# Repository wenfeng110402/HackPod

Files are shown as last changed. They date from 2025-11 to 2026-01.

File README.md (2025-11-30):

# HackPod

HackPod is my small MP3 player. It is inspired by iPod shuffle. I want a tiny music thing I can carry anywhere, so I made this. I am a middle school student. This project is for learning and for fun.

## Why I made it

- I like simple music players.
- iPod shuffle is cool and cute.
- I want to learn electronics and code.

## What it does

- Plays MP3 songs from a micro SD card.
- Buttons: Play/Pause, Next, Previous, Volume Up, Volume Down, and one extra "Hack" button.
- I2S audio to DAC/amp and a small speaker.
- LED status light.
- Battery check by ADC (shows high / medium / low).

## Parts I use

- ESP32 (microcontroller)
- Micro SD card slot
- 6 buttons
- Battery (lithium)
- Small amplifier + speaker
- My small PCB (see files in `PCB/`)

## Project files

- Firmware: `FIRMWARE/HackPod/`
- PCB files: `PCB/`
- 3D shell model: `3DSHELL/`

## Status

- Hardware works.
- Firmware is simple now. I will keep improving.

## Screenshots

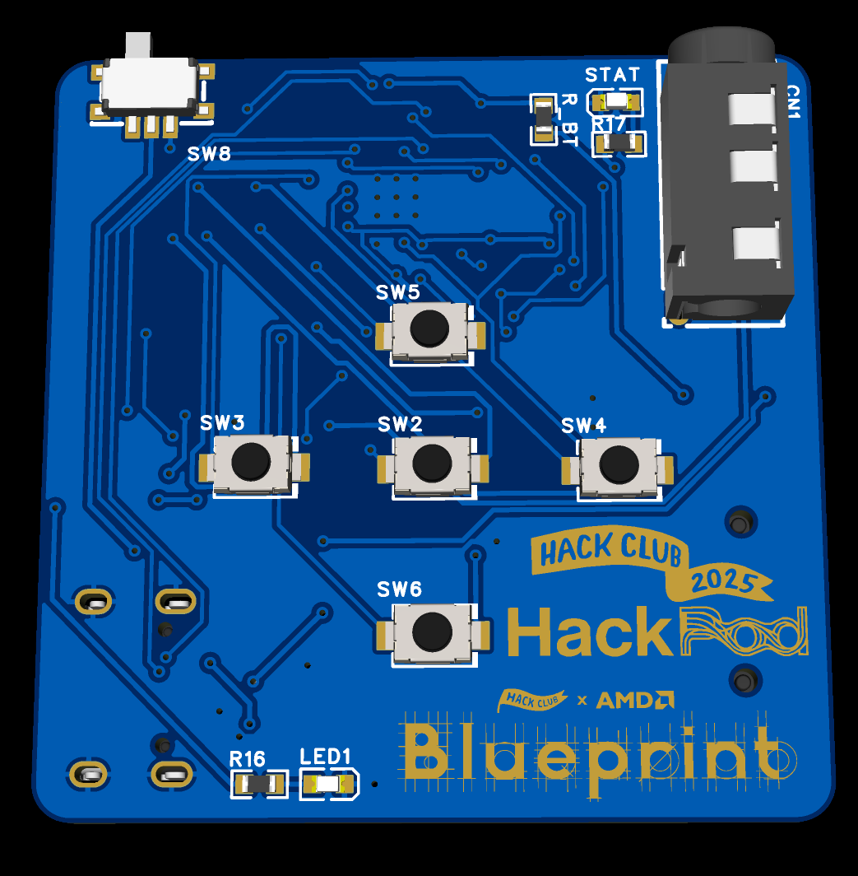
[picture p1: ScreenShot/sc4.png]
sc1

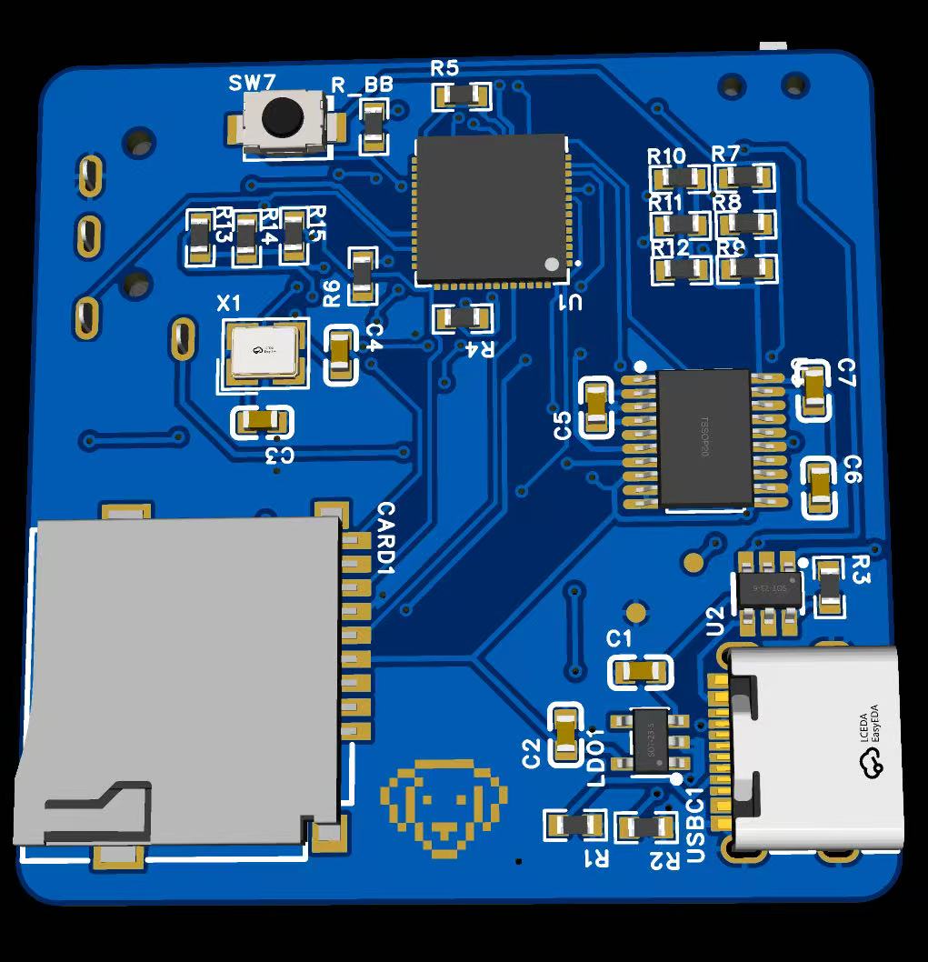
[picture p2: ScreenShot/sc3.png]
sc2

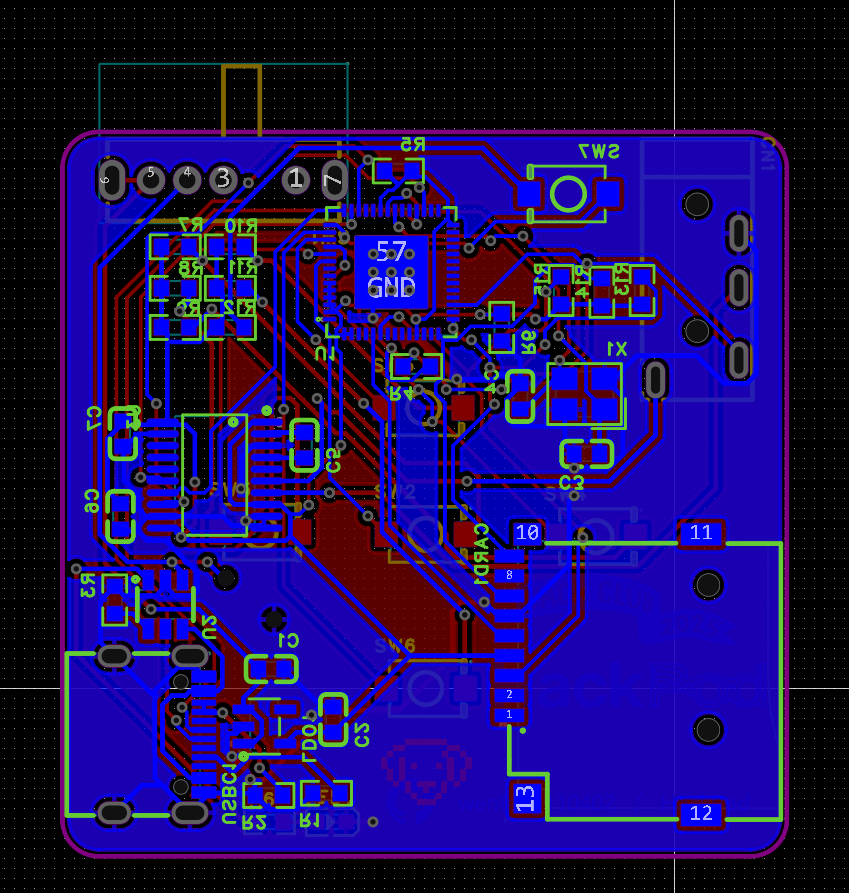
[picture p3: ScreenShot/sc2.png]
sc3

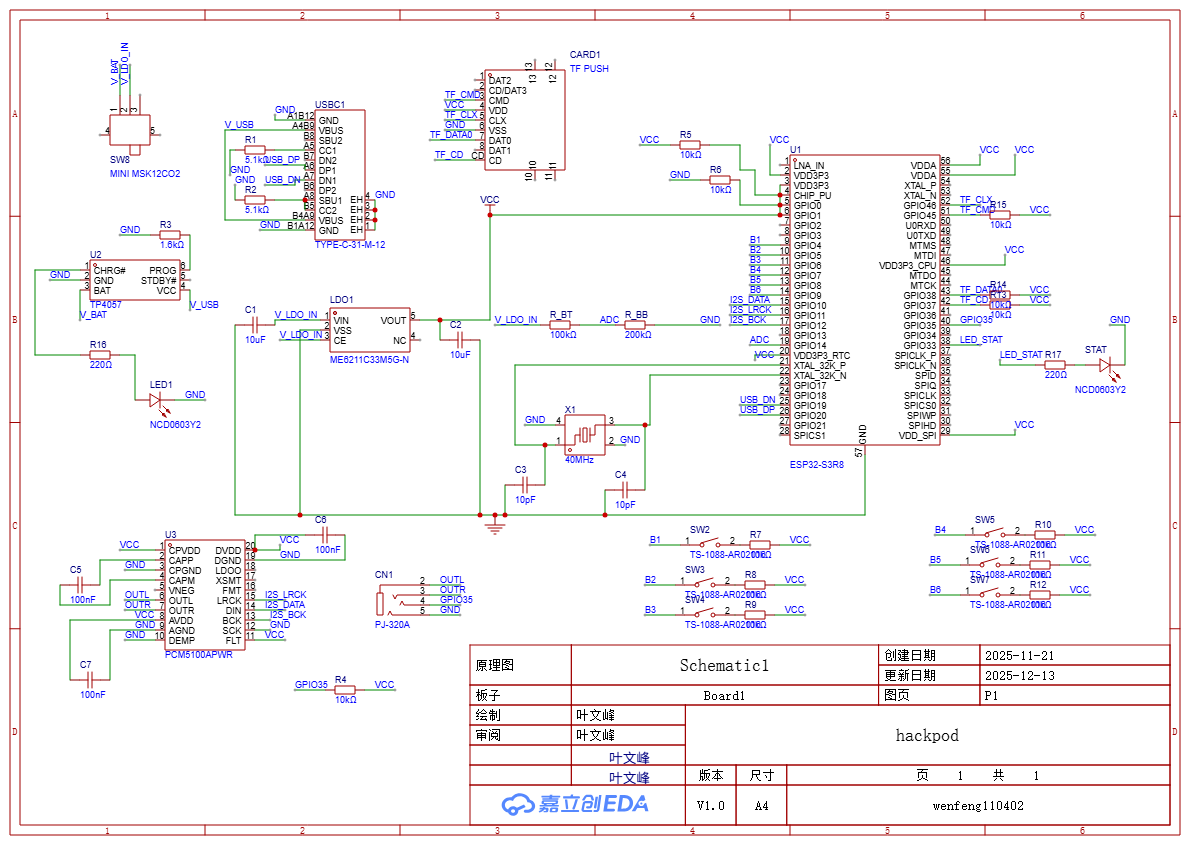
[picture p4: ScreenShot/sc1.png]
sc4


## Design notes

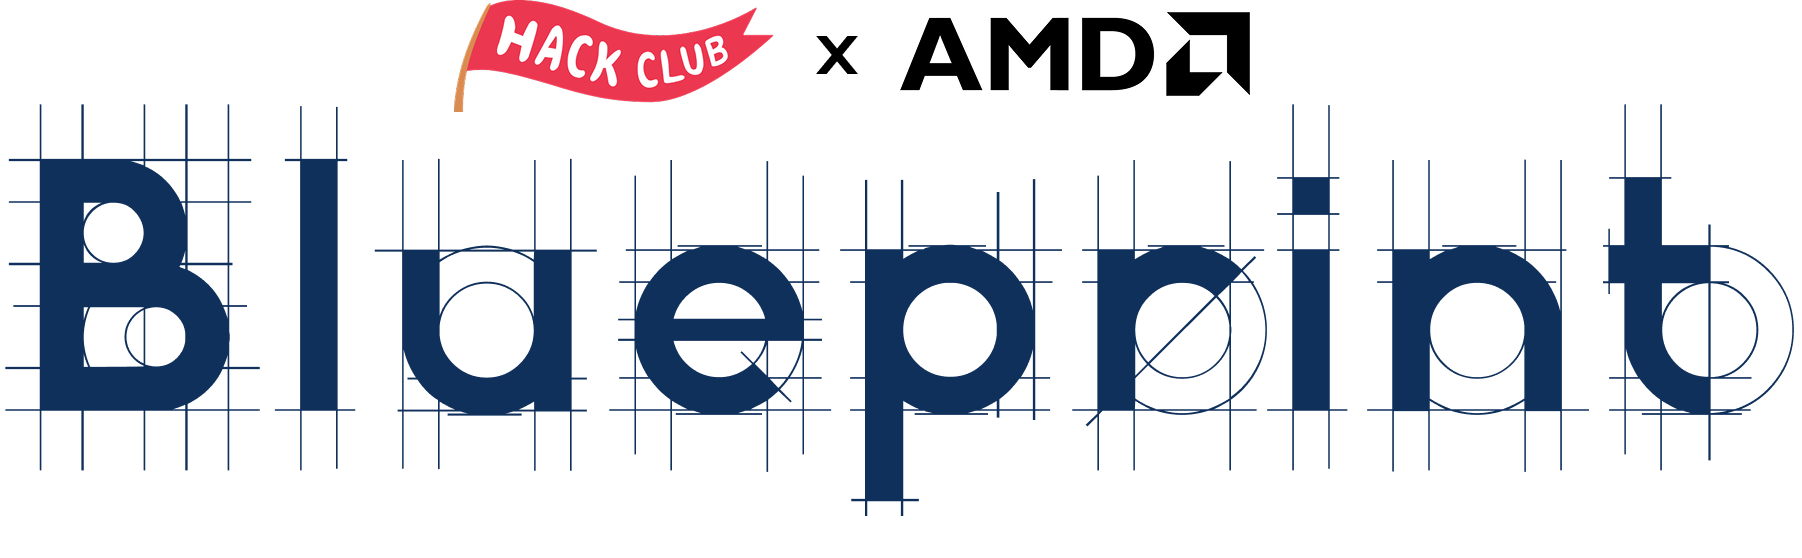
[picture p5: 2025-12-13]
posters/drive-download-20251213T033350Z-1-001/Wordmark Partnership.png

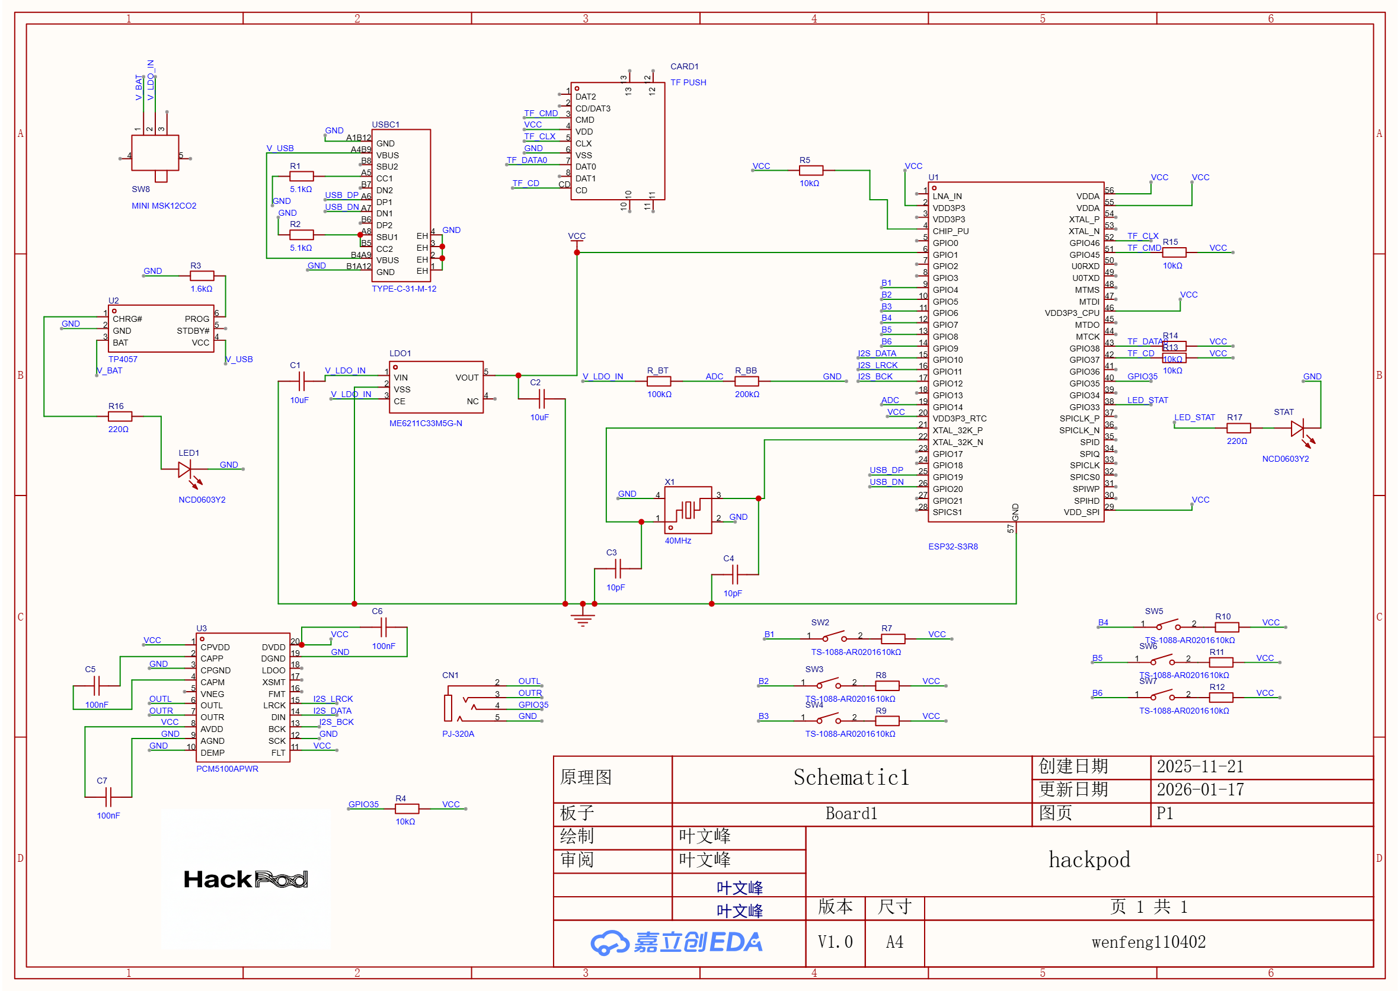
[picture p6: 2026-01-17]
PCB/SCH_Schematic1_1-P1.png

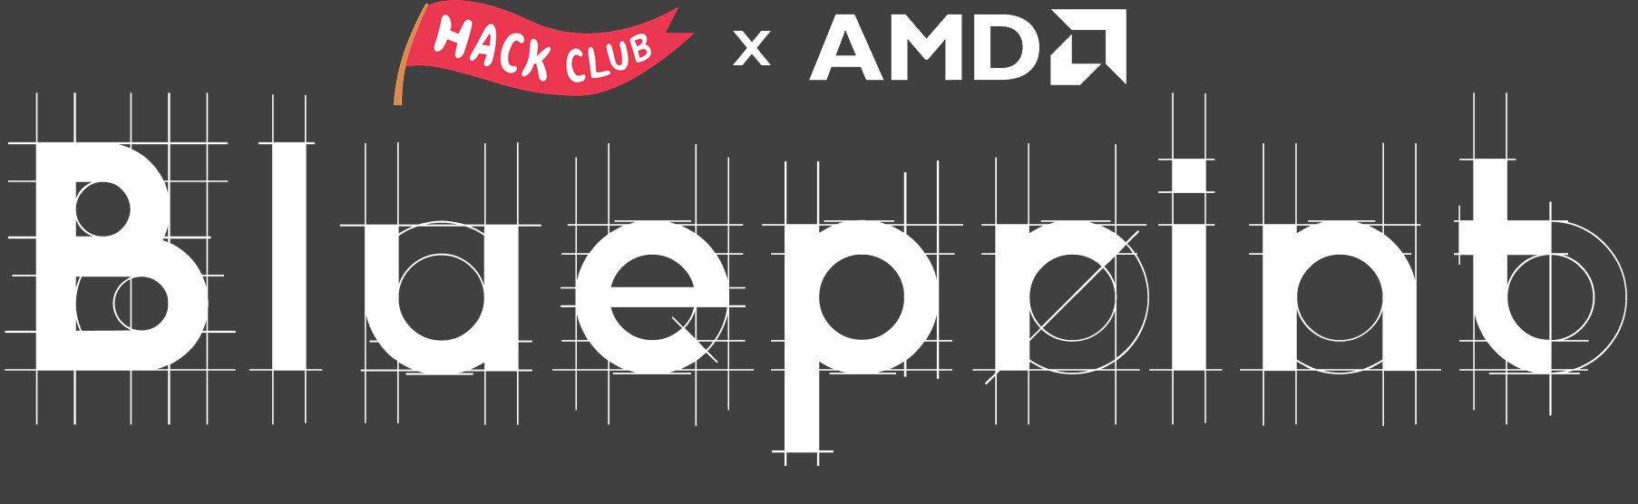
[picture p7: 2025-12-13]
posters/drive-download-20251213T033350Z-1-001/Wordmark Partnership-1.png

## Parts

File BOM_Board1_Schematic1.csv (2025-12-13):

No. | Quantity | Comment | Designator | Footprint | Value | Manufacturer Part | Manufacturer | Supplier Part | Supplier | Price(USD)
1 | 2 | 10uF | C1,C2 | C0603 | 10uF | CL10A106MA8NRNC | SAMSUNG(三星) | C96446 | LCSC | 0.3
2 | 2 | 10pF | C3,C4 | C0603 | 10pF | CL10C100JB8NNNC | SAMSUNG(三星) | C1634 | LCSC | 0.443
3 | 3 | 100nF | C5,C6,C7 | C0603 | 100nF | CL10B104KB8NNNC | SAMSUNG(三星) | C1591 | LCSC | 0.23
4 | 1 | TF PUSH | CARD1 | TF-SMD_TF-PUSH |  | TF PUSH | SHOU HAN(首韩) | C393941 | LCSC | 0.57
5 | 1 | PJ-320A | CN1 | AUDIO-TH_PJ-320A_C49284721 |  | PJ-320A | XUNPU(讯普) | C49284721 | LCSC | 0.57
6 | 1 | ME6211C33M5G-N | LDO1 | SOT-23-5_L3.0-W1.7-P0.95-LS2.8-BL |  | ME6211C33M5G-N | MICRONE(南京微盟) | C82942 | LCSC | 0.43
7 | 2 | NCD0603Y2 | LED1,STAT | LED0603-RD |  | NCD0603Y2 | 国星光电 | C89811 | LCSC | 0.08
8 | 2 | 5.1kΩ | R1,R2 | R0603 | 5.1kΩ | 0603WAF5101T5E | UNI-ROYAL(厚声) | C23186 | LCSC | 0.09
9 | 1 | 1.6kΩ | R3 | R0603 | 1.6kΩ | ERA3AEB162V | PANASONIC(松下) | C473232 | LCSC | 0.34
10 | 12 | 10kΩ | R4,R5,R6,R7,R8,R9,R10,R11,R12,R13,R14,R15 | R0603 | 10kΩ | 0603WAF1002T5E | UNI-ROYAL(厚声) | C25804 | LCSC | 0.08
11 | 2 | 220Ω | R16,R17 | R0603 | 220Ω | FRC0603J221 TS | FOJAN(富捷) | C2907127 | LCSC | 0.07
12 | 1 | 200kΩ | R_BB | R0603 | 200kΩ | ERA3AEB204V | PANASONIC(松下) | C473261 | LCSC | 0.32
13 | 1 | 100kΩ | R_BT | R0603 | 100kΩ | ERJ3EKF1003V | PANASONIC(松下) | C189597 | LCSC | 0.53
14 | 1 | SK13D07VG4 | SW8 | SW-TH_SK13D07VG4 |  | SK13D07VG4 | SHOU HAN(首韩) | C2681581 | LCSC | 0.57
15 | 6 | TS-1088-AR02016 | SW2,SW3,SW4,SW5,SW6,SW7 | SW-SMD_L3.9-W3.0-P4.45 |  | TS-1088-AR02016 | XUNPU(讯普) | C720477 | LCSC | 0.76
16 | 5 | ESP32-S3R8 | U1 | QFN-56_L7.0-W7.0-P0.40-TL-EP4.0 |  | ESP32-S3R8 | ESPRESSIF(乐鑫) | C2913194 | LCSC | 9.04
17 | 10 | TP4057 | U2 | SOT-23-6_L2.9-W1.6-P0.95-LS2.8-BR |  | TP4057 | UMW(友台半导体) | C725791 | LCSC | 0.35
18 | 5 | PCM5100APWR | U3 | TSSOP-20_L6.5-W4.4-P0.65-LS6.4-BL |  | PCM5100APWR | TI(德州仪器) | C131154 | LCSC | 4.25
19 | 1 | MINI MSK12CO2 | SW8 | SW-SMD_MSK12CO2 |  | MINI MSK12CO2 | SHOU HAN(首韩) | C2681570 | LCSC | 0.5
20 | 1 | TYPE-C-31-M-12 | USBC1 | USB-C_SMD-TYPE-C-31-M-12_1 |  | TYPE-C-31-M-12 | 韩国韩荣 | C165948 | LCSC | 0.8
21 | 10 | 40MHz | X1 | CRYSTAL-SMD_4P-L3.2-W2.5-BL | 40MHz | XL2EL89CPI-111YLC-40M | YXC(扬兴晶振) | C5444549 | LCSC | 0.53
 |  |  |  |  |  |  |  |  | BOM | 20.85
 |  |  |  |  |  |  |  |  | PCB | 44.71
 |  |  |  |  |  |  |  |  |  | 65.56

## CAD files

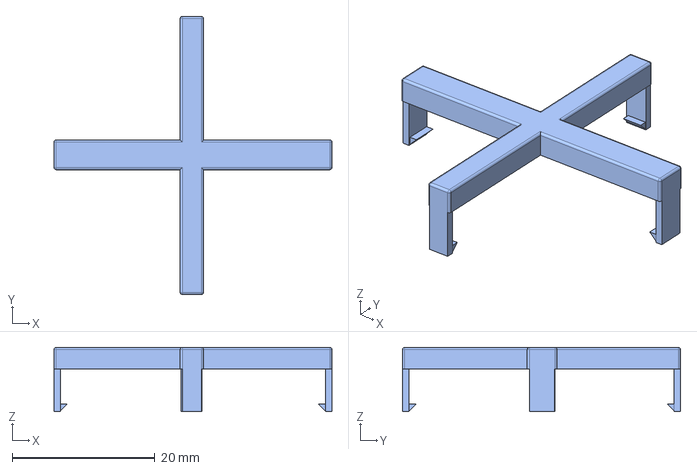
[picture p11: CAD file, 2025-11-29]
3DSHELL/shapr3d_HackPod.step
39.0 x 39.0 x 9.00 mm

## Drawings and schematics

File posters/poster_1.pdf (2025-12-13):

# Get a $400 grant

# to build a

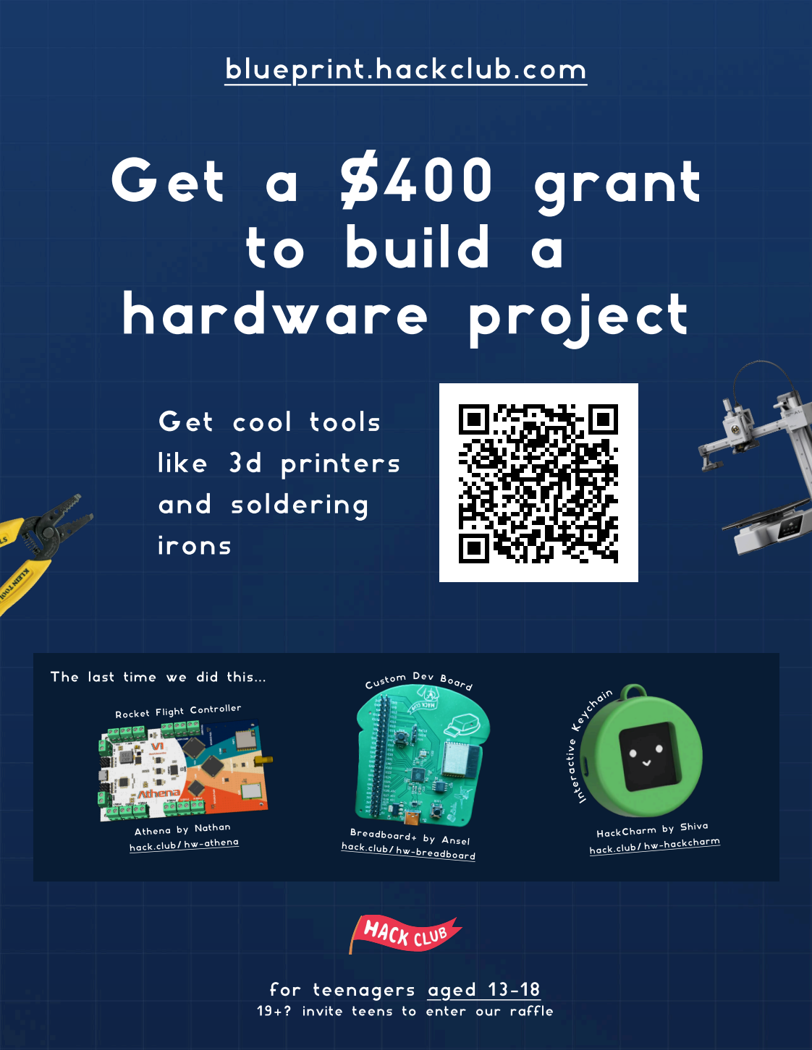
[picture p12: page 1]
hardware project; teractiv; Keychain

blueprint.hackclub.com

Get cool tools
like 3d printers
and soldering
irons

The last time we did this...

Custom Dev Board

Rocket Flight Controller

Athena by Nathan

HackCharm by Shiva

hack.club/hw-athena Breadboard+ by Ansel

hack.club/hw-breadboard

hack.club/hw-hackcharm

for teenagers aged 13-18

19+? invite teens to enter our raffle

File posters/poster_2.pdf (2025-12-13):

# Get a $400 grant

# to build a

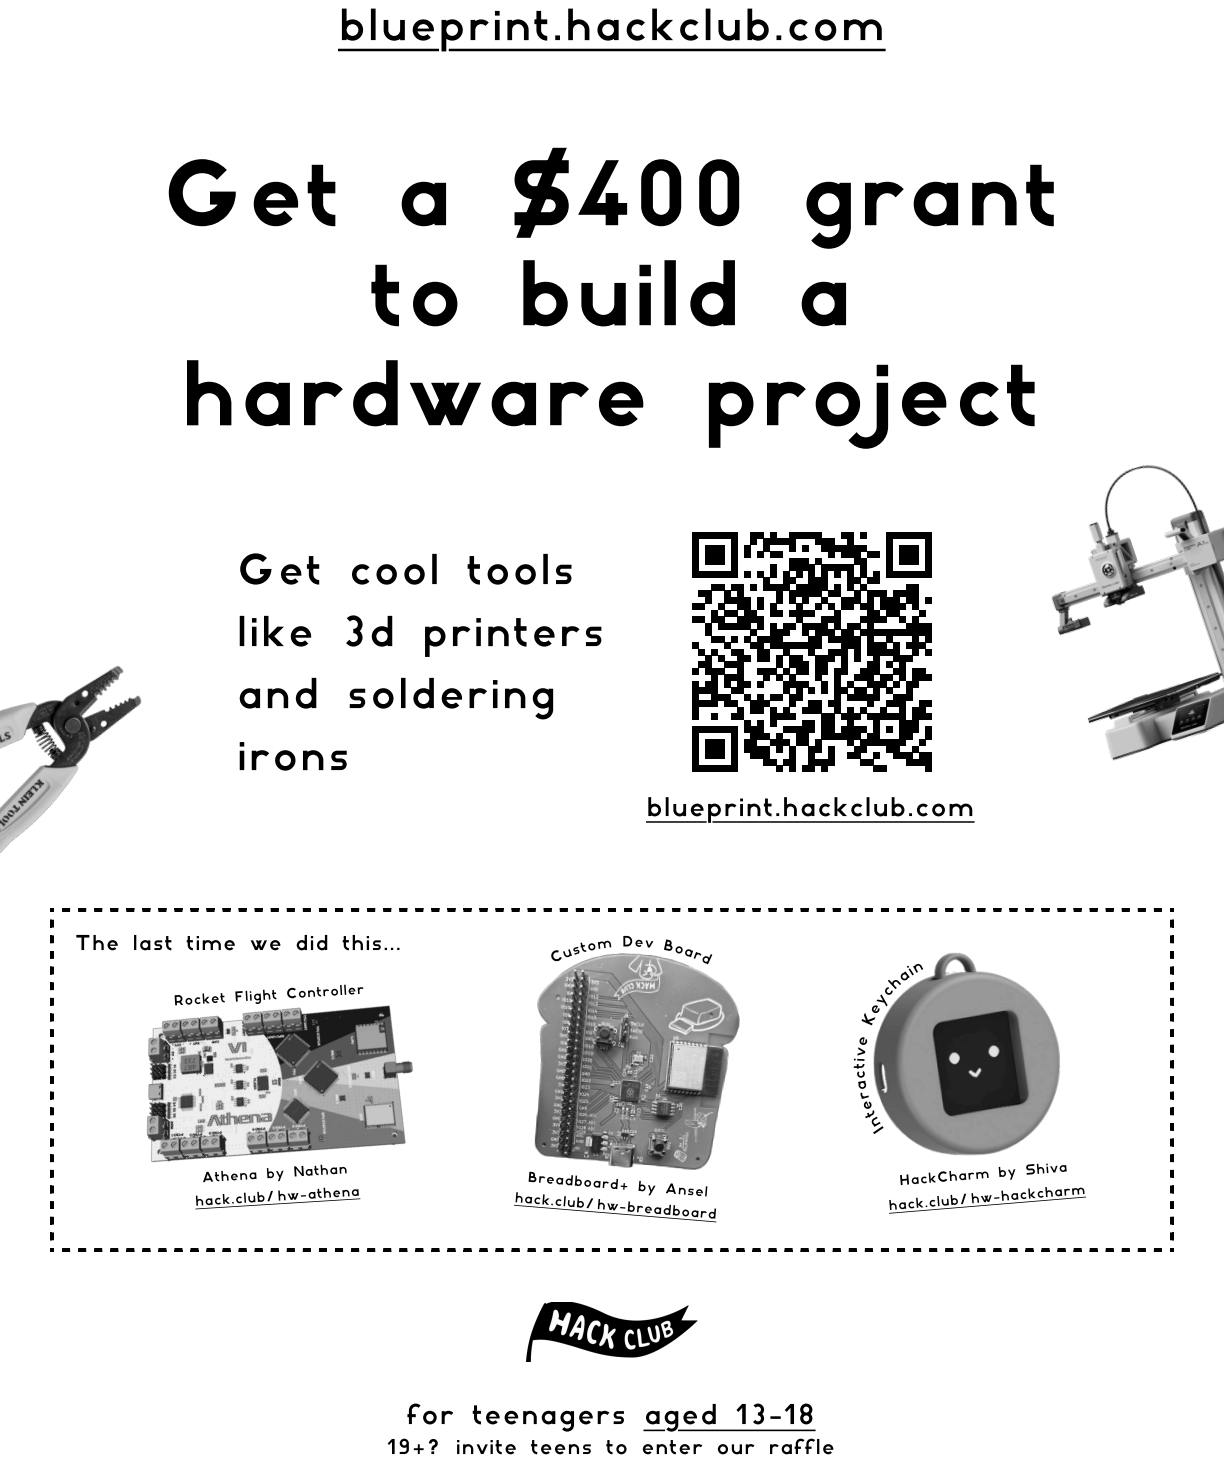
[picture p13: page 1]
hardware project; teractiv; Keychain; like 3d printers; and soldering; irons

blueprint.hackclub.com

Get cool tools

The last time we did this...

Custom Dev Board

Rocket Flight Controller

HackCharm by Shiva

hack.club/hw-athena Breadboard+ by Ansel

Athena by Nathan

hack.club/hw-breadboard

hack.club/hw-hackcharm

for teenagers aged 13-18

19+? invite teens to enter our raffle

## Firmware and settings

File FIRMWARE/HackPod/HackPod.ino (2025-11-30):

#include "config.h"
#include "PowerManager.h"
#include "InputManager.h"
#include "AudioManager.h"

// 实例化全局管理器对象
PowerManager powerMgr;
InputManager inputMgr;
// audioMgr 已经在 AudioManager.cpp 中定义

// 全局变量：
bool isAutomixMode = false; // 是否处于 Automix 模式 (现在称为随机播放模式)
static bool hasLowBatteryWarningPlayed = false; // 用于控制低电量警告只播放一次

// --- 核心逻辑：处理按键动作 ---
void handleInputAction(const char* action) {
    Serial.printf("Action: %s\n", action);

    if (strcmp(action, "PLAY") == 0) {
        audioMgr.playPause();
    } else if (strcmp(action, "NEXT") == 0) {
        audioMgr.next();
    } else if (strcmp(action, "PREV") == 0) {
        audioMgr.prev();
    } else if (strcmp(action, "VOLUP") == 0) {
        audioMgr.changeVolume(1);
    } else if (strcmp(action, "VOLDOWN") == 0) {
        audioMgr.changeVolume(-1);
    } else if (strcmp(action, "HACK_CLICK") == 0) {
        // Hack键单击：播报电量
        String batStatusFilePrefix = powerMgr.getBatteryStatusString(); // 返回 bv00, bv01 等
        String audioFile = String(SYSTEM_AUDIO_DIR) + "/" + batStatusFilePrefix + ".wav"; // 拼接成 /system/bv00.wav
        audioMgr.playSystemSound(audioFile);
    } else if (strcmp(action, "HACK_LONG") == 0) {
        // Hack键长按：切换播放模式 (随机播放 / 循环播放)
        PlayMode currentMode = audioMgr.getPlayMode();
        if (currentMode == PLAYMODE_LOOP_ALL) {
            audioMgr.setPlayMode(PLAYMODE_RANDOM);
            audioMgr.playSystemSound(String(SYSTEM_AUDIO_DIR) + "/sn02.wav"); // 播放切换到随机模式的提示音
            Serial.println("Switched to Random Play Mode.");
        } else { // 当前是随机播放模式，切换回循环播放
            audioMgr.setPlayMode(PLAYMODE_LOOP_ALL);
            audioMgr.playSystemSound(String(SYSTEM_AUDIO_DIR) + "/sn03.wav"); // 播放切换到循环模式的提示音
            Serial.println("Switched to Loop All Mode.");
        }
        // LED 指示：长按 Hack 键时，LED 闪烁一下或改变状态
        digitalWrite(LED_STAT_PIN, HIGH);
        delay(100);
        digitalWrite(LED_STAT_PIN, LOW);
    }
}

void setup() {
    Serial.begin(115200);
    Serial.println("\n--- HackPod Starting ---");

    // 初始化 LED
    pinMode(LED_STAT_PIN, OUTPUT);
    digitalWrite(LED_STAT_PIN, LOW);

    // 初始化各个模块
    powerMgr.begin();
    // 传入回调函数，让 InputManager 知道按键触发时通知谁
    inputMgr.begin(handleInputAction);
    audioMgr.begin();

    // 播放开机音 (如果需要，可以在 system 文件夹放一个 power_on.wav)
    // audioMgr.playSystemSound(String(SYSTEM_AUDIO_DIR) + "/power_on.wav");

    Serial.println("--- Ready ---");
}

void loop() {
    // 必须在主循环中不断调用这些函数
    audioMgr.loop();
    inputMgr.loop();

    // --- 1. 电池状态更新与打印 & 低电量警告 ---
    // 每隔5秒读取并打印一次电池信息
    static unsigned long lastBatteryReadTime = 0;
    if (millis() - lastBatteryReadTime > 5000) { // 每5秒读取一次
        float voltage = powerMgr.getBatteryVoltage();
        int percentage = powerMgr.getBatteryPercentage();
        // getBatteryStatusString 现在返回 "bv00" 等文件名部分，这里仅用于打印
        String statusPrefix = powerMgr.getBatteryStatusString(); 

        Serial.print("Battery: ");
        Serial.print(voltage, 2); 
        Serial.print("V (");
        Serial.print(percentage);
        Serial.print("%), Status: ");
        Serial.println(statusPrefix); // 打印文件名后缀

        // 低电量警告逻辑 (仅当电量低于10%且未播放过警告时才播放)
        if (percentage <= 10 && !hasLowBatteryWarningPlayed) {
            audioMgr.playSystemSound(String(SYSTEM_AUDIO_DIR) + "/bn00.wav"); // 播放低电量警告音
            Serial.println("!! Low Battery Warning (10%) !!");
            hasLowBatteryWarningPlayed = true; // 设置标志，防止重复播放
        } else if (percentage > 10) {
            hasLowBatteryWarningPlayed = false; // 电量回升后重置警告标志
        }

        // LED 指示：如果电量低于20%，LED 慢速闪烁
        if (percentage < 20) {
            digitalWrite(LED_STAT_PIN, (millis() / 1000) % 2); // 每1秒闪烁一次
        } else if (audioMgr.getPlayMode() == PLAYMODE_RANDOM) {
            // 如果处于随机播放模式，LED 保持常亮（或者其他指示方式）
            digitalWrite(LED_STAT_PIN, HIGH);
        }
        else {
            digitalWrite(LED_STAT_PIN, LOW); // 正常电量且非随机模式，LED 关闭
        }

        lastBatteryReadTime = millis();
    }
    
    // --- 2. Automix 模式 LED 指示 (现在是随机播放模式) ---
    // 如果是随机播放模式，LED 持续亮起（或者有规律闪烁）
    // 这个逻辑已经整合到上面的电池状态 LED 逻辑中，避免冲突
    
}

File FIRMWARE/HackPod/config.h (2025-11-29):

#ifndef CONFIG_H
#define CONFIG_H

// 1.i2s dac
#define I2S_BCK_PIN 12
#define I2S_LRCK_PIN 11
#define I2S_DATA_PIN 10    //data out pin

// 2.sdcard
#define SD_CLX_PIN 46
#define SD_CMD_PIN 45
#define SD_D0_PIN 38
#define SD_CD_PIN 37

// 3.buttons
#define B_PP_PIN 4 //play/pause
#define B_NEXT_PIN 6
#define B_PREV_PIN 5
#define B_VU_PIN 7
#define B_VD_PIN 8
#define B_HACK_PIN 9

// 4.BattVolt ADC
#define BAT_ADC_PIN 14

// 5.LEDStatus
#define LED_STAT_PIN 33

// --- 6. 其他配置常量 ---
#define DEFAULT_VOLUME      15 // 默认音量 (ESP32-audioI2S 库通常是 0-21)
#define BATTERY_MAX_VOLT    4.20f // 电池充满时的电压
#define BATTERY_MIN_VOLT    3.30f // 电池低电量时的电压 (低于此值可能关机或警告)
#define BATTERY_SAMPLES     50   // ADC 读取平均采样次数，用于提高精度，减少噪声
// 电池分压电阻值，用于计算实际电压
#define VOLTAGE_DIVIDER_R1  100000.0f // R_BAT_TOP 100k欧姆
#define VOLTAGE_DIVIDER_R2  200000.0f // R_BAT_BOTTOM 200k欧姆
#define ADC_REFERENCE_VOLTAGE 3.3f    // ESP32-S3 ADC 的参考电压 (LDO输出给ESP32的电压)
#define ADC_MAX_READING     4095.0f   // ESP32-S3 ADC 的最大读数 (12位ADC)

// --- 7. 系统文件路径 ---
// 用于存放电量播报音频的文件夹和文件名前缀
#define SYSTEM_AUDIO_DIR    "/system"
#define BAT_AUDIO_PREFIX    "battery_" // 例如 battery_high.mp3, battery_medium.mp3

#endif // CONFIG_H 结束宏定义

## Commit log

2025-11-29 new update！
    [shapr3d_HackPod.step]
2025-12-06 add bom
    [BOM_Board1_Schematic1.csv, BOM_HackPod.xlsx]
2025-12-13 upload price
    [BOM_Board1_Schematic1.csv]
2025-12-13 update the appearance
    [BOM_Board1_Schematic1.csv]
2025-12-13 change the pcb price
    [BOM_Board1_Schematic1.csv]
2025-12-13 update prices
    [BOM_Board1_Schematic1.csv]
2025-12-14 更新屏幕截图
2026-01-17 Update PCB files: modified Altium_hackpod.zip and SCH_Schematic1_1-P1.png
    [1_P1.schdoc]
